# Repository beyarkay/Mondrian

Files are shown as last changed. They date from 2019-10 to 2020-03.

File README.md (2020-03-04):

# Mondrian

Last Updated: 10 November 2019

A robot to draw on a flat surface, with local positioning done through a moving phone camera

# Next Steps

* Add a movement system:
	* 'Look at me' - the robot turns on its axis to face the camera
	* 'Follow me' - the robot continuously moves towards the camera
	* 'Trace a shape' - Find a way to upload a vector line file which the robot is able to follow and trace out
* Add a second view to the app, which shows the world from a top-down perspective. This makes it easier to draw, with your finger, the path you want the robot to take. Maybe the original 'camera' view is shown as a little floating window in the corner, like google maps?
* Add a sleep timer, that will HALT the robot after a certain amount of inactivity
* Add instructions for how to connect to the robot
* Add in a dedicated isolation switch that will disconnect the EN1 and EN2 pins on the H-bridge when the ESP is starting up. (Right now this is just done via a wire that is manually moved)

# Components

## 1. The Robot

* This project will control a simple 2 wheel drive robot. 
* On board the robot, there is:
	* an Arduino nano for basic motor control logic, 
	* 2 simple DC motors for movement
	* an ESP8266-01 WiFi chip to allow the robot to communicate with an android app
	* Aruco fiducial markers used for easy computer vision.
* The robot has no means of determining it's location onboard, and relies entirely on the android app.
* The ESP8266-01 starts an access point and basic HTTP server when it's powered up to which the android app connects.

### Breadboard



### Circuit Diagram



### Example Aruco Markers

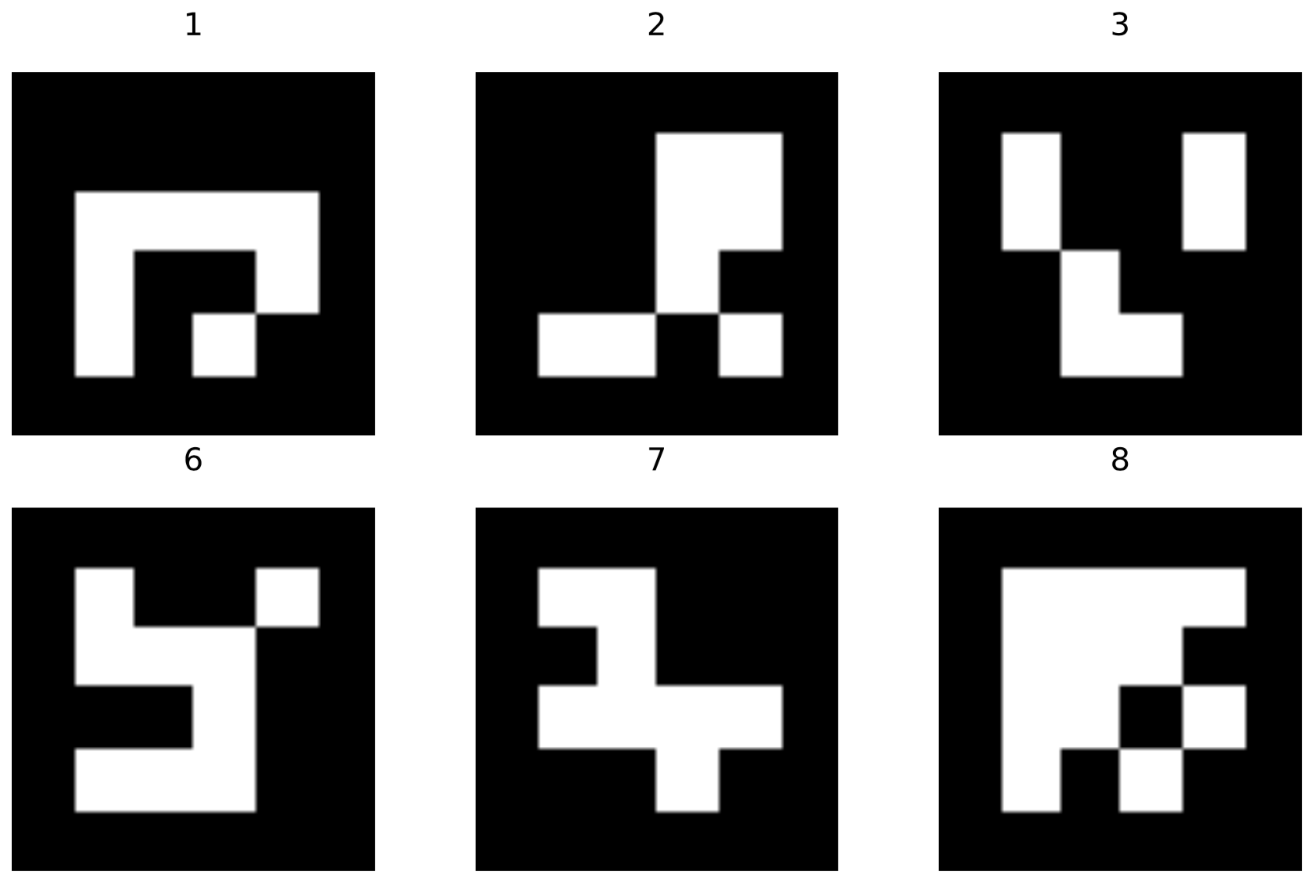
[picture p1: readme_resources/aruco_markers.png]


## 2. The Phone Camera

* An Android app uses the phone's rear camera to calculate the relative position and rotation of Aruco fiducial markers placed on the robot.
* The app can connect the phone to the robot's access point, and then communicate with the robot via a basic HTTP server setup by the robot.
* The app user can send control commands to the robot, as well as more sophisticated commands that require the information gained by the external camera viewpoint.
* With the addition of a reference Aruco marker placed on the ground, the robot could:
	* move towards the other Aruco marker on the floor
	* continuously move away from the camera / maintain a certain distance from the camera
	* trace a consistent square on the ground while the camera viewpoint changes
	* if multiple phones were used, the robot could expand its area of reliable movement to beyond that of just one camera's viewpoint by selecting the closest or most accurate viewpoint

### Prototype App Screenshots

 

# Current progress

### Marker pose estimation and surface projection

A prototype of the marker detection, pose estimation and projection onto a 2D plane has been developed.
The picture below show an image taken with a phone camera where the aruco markers have been detected. The second picture shows a projection of the marker positions and a "normal" for each marker (point showing the orientation of the marker).





### Network protocols

Prototype protocols and implementations for wireless remote debugging and receiving location updates on the ESP have been developed.

# File Structure
```
Mondrian  
├── Arduino\ and\ ESP  
│   ├── esp  
│   │   └── esp.ino  
│   ├── james.fzz  
│   ├── james.ino  
│   │   ├── james  
│   │   │   └── james.ino  
│   │   └── james.ino.ino  
│   ├── james_bb.png  
│   ├── nano  
│   │   └── nano.ino  
│   └── uno  
│       └── uno.ino  
├── Phone\ Camera  
│   ├── Aruco\ Markers.pdf  
│   └── OpenCVDeus  
│       ├── `// In here is the Android Studio Project`  
└── README.md  
```

# Uploading Code to the ESP8266

Unfortunately, the ESP8266-01 can be very finicky, but below is the best way I've found to flash it and upload code.

* Write code for the ESP8266
* Change board to 'Generic ESP8266 Module'
* Compile the code
* Connect the UNO to the computer
* Connect the UNO to the ESP8266: 
    * UNO Tx --> ESP Tx
    * UNO Rx --> ESP Rx
* Click 'Upload' on the Arduino IDE
* Then do this sequence to the following pins
    * ESP RESET --> LOW
    * ESP GPIO0 --> LOW
    * ESP RESET --> XXX
    * ESP GPIO0 --> XXX
* You might have to try this compile-button sequence a few times
before you see something like this:
```Connecting........_____....._____....._____.
Chip is ESP8266EX
Features: WiFi
...
```
* After this, push and release the RESET button, and all should 
be good
* Possible Errors: 
    * TODO: Add errors

* For the NANO, upload nano.ino, but make sure 
'ATMega 382P (Old Bootloader)' is selected

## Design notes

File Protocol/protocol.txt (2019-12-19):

max 127 markers (due to marker count being sent as signed byte)

-----------------------PAYLOAD STRUCTURE----------------------

4 bytes - time
1 byte - number of markers in this message

for each marker:
	1 byte - marker ID
	8 bytes - x
	8 bytes - y
	8 bytes - rotation

--------------------------------------------------------------

Notes for the future:

Stu's ESP8266 was using little-endian ordering (running Arduino core)

UDP_TX_PACKET_MAX_SIZE was 8192 on Stu's ESP8266
UPD packet header is 8 bytes
This leaves us with 8187 usable bytes
We are using 25 bytes per marker + 5 bytes for time + nMarkers
Therefore we could in theory do (8192-5)/25 = 327 markers

Practically we could do 256 markers by using an unsigned int for nMarkers
Currently not doing this because Java doesn't have nice support for unsigned ints - ugly conversion code needed
Remember to change the marker array size on the ESP if we do

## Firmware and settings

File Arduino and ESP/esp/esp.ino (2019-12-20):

/*
   Steps for uploading to ESP8266

   1a. Change Tools>Board to 'Generic ESP8266 Module'
   1b. Change Tools>Port to be the correct port
   1c. Compile changes
   2a. Connect USB to Arduino Nano
   2b. Connect Nano RST pin to GND
   2c. Connect ESP Rx --> Nano Rx
   2d. Connect ESP Tx --> Nano Tx
   2e. Disconnect IO2 from everything.
   3a. Hold ESP RST to GND and ESP IO0 to GND
   3b. Click upload on Arduino IDE
   3c. Wait for Arduino IDE output to read "Compiling"
   3d. Release ESP RST
   3e. Release ESP IO0
   4a. On a successful connection, you'll see something like:
  ```
  Chip is ESP8266EX
  Features: WiFi
  MAC: 2c:f4:32:0f:95:e2
  Uploading stub...
  Running stub...
  Stub running...
  Configuring flash size...
  Auto-detected Flash size: 1MB
  Flash params set to 0x0320
  Compressed 295648 bytes to 211834...

  Writing at 0x00000000... (7 %)
  Writing at 0x00004000... (15 %)
  Writing at 0x00008000... (23 %)
  Writing at 0x0000c000... (30 %)
  Writing at 0x00010000... (38 %)
  Writing at 0x00014000... (46 %)
  Writing at 0x00018000... (53 %)
  Writing at 0x0001c000... (61 %)
  Writing at 0x00020000... (69 %)
  Writing at 0x00024000... (76 %)
  Writing at 0x00028000... (84 %)
  Writing at 0x0002c000... (92 %)
  Writing at 0x00030000... (100 %)
  Wrote 295648 bytes (211834 compressed) at 0x00000000 in 18.8 seconds (effective 125.6 kbit/s)...
  Hash of data verified.

  Leaving...
  Hard resetting via RTS pin...
  ```
   4b. It is extremely finicky, so you'll have to repeat steps 3a --> 3e a couple times, usually 10 or 15
   5a. after you see these two lines:
  ```
  Leaving...
  Hard resetting via RTS pin...
  ```
   5b. Make sure ESP IO0 isn't connected to ground
   5c. Connect ESP RST to ground, then release it
   6.  The ESP will restart and run the code that you've just uploaded

   TROUBLESHOOTING

   If the ESP crashes the Exception Cause will be shown and the current stack will be dumped.
      This website has a list of exceptions and their hex number:
          https://arduino-esp8266.readthedocs.io/en/latest/exception_causes.html
      The tool EspExceptionDecoder (https://github.com/me-no-dev/EspExceptionDecoder) works to
          decode the ESP8266 Stack dump into readable error messages

   HOW TO ACCESS DEBUG LOG
   
   run the following command:
   nc 192.168.4.1 90

   you should see a friendly greeting from James
   note that for some reason it sometimes takes a while to connect
*/

#include <ESP8266WiFi.h>
#include <ESP8266WebServer.h>

#include <ESP8266mDNS.h>
#include <WiFiUdp.h>
#include <ArduinoOTA.h>

static_assert (sizeof(byte) == 1, "byte size is incompatible with map update protocol");
static_assert (sizeof(int) == 4, "int size is incompatible with map update protocol");
static_assert (sizeof(double) == 8, "double size is incompatible with map update protocol");

const char* ssid = "riversong";
const char* password = "melodypond";

const unsigned int map_updates_port = 8888;             //port to listen for UDP map updates on
const unsigned int log_server_port = 90;                //port to listen for TCP debug connections on
const unsigned int remote_control_web_server_port = 80; //web server port for remote control commands
const unsigned int OTA_updates_port = 8266;             //port for OTA updates server

const int MAX_MARKERS = 127;
const int LOG_BUFFER_SIZE = 500;

struct marker {
  double x, y, rotation;
};

char log_buffer[LOG_BUFFER_SIZE];
int log_buffer_start = 0;
int log_buffer_end = 0;

//Note "markers" and "marker_seen" are indexed by marker ID, but "incoming_markers" and "incoming_marker_ids" are not
byte incoming_markers_size = 0; //Number of markers received in the last packet (currently in the incoming_markers and incoming_marker_ids arrays)
byte incoming_marker_ids[MAX_MARKERS]; //ID of each incoming marker
marker incoming_markers[MAX_MARKERS]; //Parallel array to incoming_marker_ids

//Below are 2 arrays that aren't currently used anywhere in the code
boolean marker_seen[MAX_MARKERS]; //for future use - indexed by ID
marker markers[MAX_MARKERS];  //for future use - indexed by ID

byte packetBuffer[UDP_TX_PACKET_MAX_SIZE + 1]; //buffer to hold incoming packet for map updates

WiFiUDP Udp;
WiFiServer log_server(log_server_port);
WiFiClient log_client; // currently connected logging client
ESP8266WebServer server(remote_control_web_server_port);

String makeHtmlForm(String state) {
  String form = String("<meta name=\"viewport\" content=\"initial-scale=1.0, maximum-scale=1.0, user-scalable=no\" />") +
                "<form action='led'>" +
                "<input type='radio' name='state' value='on' checked>Turn On" +
                "<br /><br />" +
                "<input type='radio' name='state' value='off'>Turn Off" +
                "<br /><br />" +
                "<input type='submit' value='Submit'>" +
                "</form>" +
                "<p>Status: " +
                state +
                "</p>" +
                "<br />" +
                "<a href='/serial?data=f'>Send '/serial?data=f'</a>" +
                "<br />" +
                "<a href='/serial?data=b'>Send '/serial?data=b'</a>" +
                "<br />" +
                "<a href='/serial?data=r'>Send '/serial?data=r'</a>" +
                "<br />" +
                "<a href='/serial?data=l'>Send '/serial?data=l'</a>" +
                "<br />" +
                "<a href='/serial?data=h'>Send '/serial?data=h'</a>";
  return form;
}

void handleSerial() {
  // Get the input from the client
  String data = server.arg("data"); //http ://<ip address>/serial?data=thisissomedata
  char cmd = 'h';
  if (data.length() > 0)
    cmd = data.charAt(0);

  if (cmd == 'r') {
    digitalWrite(0, LOW);
    digitalWrite(1, HIGH);
    digitalWrite(2, LOW);
    digitalWrite(3, HIGH);
  } else if (cmd == 'l') {
    digitalWrite(0, HIGH);
    digitalWrite(1, LOW);
    digitalWrite(2, HIGH);
    digitalWrite(3, LOW);
    
  } else if (cmd == 'f') {
    digitalWrite(0, HIGH);
    digitalWrite(1, LOW);
    digitalWrite(2, LOW);
    digitalWrite(3, HIGH);
  } else if (cmd == 'b') {
    digitalWrite(0, LOW);
    digitalWrite(1, HIGH);
    digitalWrite(2, HIGH);
    digitalWrite(3, LOW);
  } else if (cmd == 'h') {
    digitalWrite(0, LOW);
    digitalWrite(1, LOW);
    digitalWrite(2, LOW);
    digitalWrite(3, LOW);
  } else if (cmd == '0') {
    digitalWrite(0, HIGH);
    digitalWrite(1, LOW);
    digitalWrite(2, LOW);
    digitalWrite(3, LOW);
  } else if (cmd == '1') {
    digitalWrite(0, LOW);
    digitalWrite(1, HIGH);
    digitalWrite(2, LOW);
    digitalWrite(3, LOW);
  } else if (cmd == '2') {
    digitalWrite(0, LOW);
    digitalWrite(1, LOW);
    digitalWrite(2, HIGH);
    digitalWrite(3, LOW);
  } else if (cmd == '3') {
    digitalWrite(0, LOW);
    digitalWrite(1, LOW);
    digitalWrite(2, LOW);
    digitalWrite(3, HIGH);
  }
  // Send a confirmation response to the client
  server.send(200, "text/html", makeHtmlForm(data));
}

//void handleLed() {
//  String state = server.arg("state");
//  if (state == "on") {  //http ://<ip address>/led?state=on
//    digitalWrite(LED_BUILTIN, HIGH);
//  }
//  else if (state == "off") {  // http ://<ip address>/led?state=off
//    digitalWrite(LED_BUILTIN, LOW);
//  }
//  server.send(200, "text/html", makeHtmlForm(state));
//}\


void setup() {
  pinMode(0, OUTPUT);
  pinMode(1, OUTPUT);
  pinMode(2, OUTPUT);
  pinMode(3, OUTPUT);

  digitalWrite(0, LOW);
  digitalWrite(1, LOW);
  digitalWrite(2, LOW);
  digitalWrite(3, LOW);

  WiFi.softAP(ssid, password);             // Start the access point
  ArduinoOTA.setPort(OTA_updates_port);
  ArduinoOTA.begin();

  Udp.begin(map_updates_port);
  log_server.begin();

  // Setup the endpoints for the server:
  server.on("/", []() {
    server.send(200, "text/html", makeHtmlForm("unknown"));
  });
//  server.on("/led", handleLed);
  server.on("/serial", handleSerial);

  server.begin();
}

void loop() {
  ArduinoOTA.handle();
  server.handleClient();
  handleLogServer();
  handleMapUpdates();
}

void handleMapUpdates() {
  // if there's data available, read a packet
  int packetSize = Udp.parsePacket();
  if (packetSize) {
    // read the packet into packetBufffer
    int n = Udp.read(packetBuffer, UDP_TX_PACKET_MAX_SIZE);
    packetBuffer[n] = 0;

    byte* pointer = packetBuffer;

    int time;
    memcpy(&time, pointer, 4);                  pointer += 4;
    memcpy(&incoming_markers_size, pointer, 1); pointer += 1;

    logf("Received packet time: %d, markers: %d\n", time,  incoming_markers_size);

    for (byte i = 0; i < incoming_markers_size; i++) {
      memcpy(&incoming_marker_ids[i], pointer, 1);       pointer += 1;
      memcpy(&incoming_markers[i].x, pointer, 8);        pointer += 8;
      memcpy(&incoming_markers[i].y, pointer, 8);        pointer += 8;
      memcpy(&incoming_markers[i].rotation, pointer, 8); pointer += 8;
      
      logf("Marker id: %d, x: %f, y: %f, rotation: %f\n", incoming_marker_ids[i], incoming_markers[i].x, incoming_markers[i].y, incoming_markers[i].rotation);
    }
  }
}

void handleLogServer() {
  WiFiClient new_client = log_server.available();
  if (new_client) {
    if (log_client.connected()) {
      new_client.println("hi, you've reached James.\nSorry I can't take this connection right now, someone else is still using the debug connection.");
      new_client.stop();
    } else {
      log_client = new_client;
      log_client.println("hi, this is James.");
    }
  }

  //Send everything currently in the log buffer
  if (log_client.connected()) {
    while (log_buffer_start != log_buffer_end) {
      log_client.print(log_buffer[log_buffer_start]);
      log_buffer_start = (log_buffer_start + 1) % LOG_BUFFER_SIZE;
    }
    log_client.flush();
  }
}

/**
   Copied from the printf function at: https://github.com/esp8266/Arduino/blob/master/cores/esp8266/Print.cpp
*/
void logf(const char *format, ...) {
  va_list arg;
  va_start(arg, format);
  char temp[64];
  char* buffer = temp;
  size_t len = vsnprintf(temp, sizeof(temp), format, arg);
  va_end(arg);
  if (len > sizeof(temp) - 1) {
    buffer = new char[len + 1];
    if (!buffer) {
      return;
    }
    va_start(arg, format);
    len = vsnprintf(buffer, len + 1, format, arg);
    va_end(arg);
  }
  log(buffer);
  if (buffer != temp) {
    delete[] buffer;
  }
}

void log(char s[]) {
  for (int i = 0; s[i] != 0; i++) {
    log_buffer[log_buffer_end] = s[i];
    log_buffer_end = (log_buffer_end + 1) % LOG_BUFFER_SIZE;

    //If the buffer is full, we're going to overwrite the oldest element next
    if (log_buffer_start == log_buffer_end) {
      log_buffer_start = (log_buffer_start + 1) % LOG_BUFFER_SIZE;
    }
  }
}

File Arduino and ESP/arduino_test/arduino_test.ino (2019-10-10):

bool setupComplete = false;

void setup() {
  // put your setup code here, to run once:
  Serial.begin(115200);
  pinMode(LED_BUILTIN, OUTPUT);

}

void loop() {

  // put your main code here, to run repeatedly:
  char command = readByte();
  if (command == 's') {
    setupComplete = true;
  } else if (command == 'h' && setupComplete) {
    digitalWrite(LED_BUILTIN, HIGH);
  } else if (command == 'l' && setupComplete) {
    digitalWrite(LED_BUILTIN, LOW);
  }


}


int readByte() {
  /*
     Wait until a byte is available, then read and return it
  */
  byte incomingByte = '\n';
  while (incomingByte == '\n') {
    while (Serial.available() == 0);
    incomingByte = (char) Serial.read();
  }
  //  Serial.println(incomingByte);
  return incomingByte;
}

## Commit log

2019-10-23 Made UI more powerful, improved reliability of the ESP connection
2019-11-10 added fritzing circuit diagram
    [james.fzz]
2019-11-11 free from the shackles of the Arduino
2019-11-23 Added Jupyter notebook for generating planar Aruco boards
2019-12-03 setting up jupyter notebook for calibration and recognition
2019-12-16 added magic mafs prototype
